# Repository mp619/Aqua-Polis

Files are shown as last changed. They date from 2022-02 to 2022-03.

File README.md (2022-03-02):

# Imperial College EEE - ELEC60013 Embedded Systems

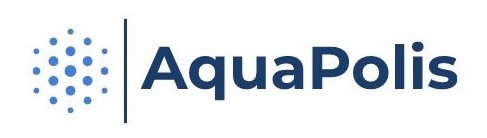
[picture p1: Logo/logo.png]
akt text


## Aquapolis

We often focus on the scarcity of water, yet the quality of it is as problematic: unsafe
water is in the top 15 causes of death worldwide, counting more than 1.2 million
victims only in 2017, as a study by the OurWorldInData highlights. This does not
affect only rural areas but also urban ones, as in the recent case of the Flint Water
Crisis.

In addition to health implications, this represents an environmental and economical problem as well: as reported from the CDP Global Water Report 2020, water
security is a necessary issue to solve in order to achieve our Net Zero Goal and the
multiple studies indicates how the financial impact of water risks is more than 5
times greater than the cost of addressing them.

The first step to solve this problem is to have a closer insight into the quality of the
water globally, integrating the data sets already present with new data collected by
individuals and institutions on a local scale. We believe that only through collective
intelligence we can assure our model and predictions are up to date and can meet
the highest quality standards.

From this vision was born AquaPolis, a network of IoT water sensors that can provide an accessible solution both in the immediate and long-term future. Each device can collect measurements of the water’s quality at any time, generating predictions on its potability based on a Machine Learning Model trained on big, verified
data sets. In addition, the new data, uploaded on a map, helps the model make better predictions in the future, keeping track of the values locally and creating a more
accurate view of the water situation globally.

## Structure

```bash
.
├───communication             # Communication testing files
├───Logo                      # Logo
├───Main                      # Raspi Source Files with modules
├───Miscellaneous             # Diagrams and MATLAB files for user guide
├───ML models                 # ML models
├───Protype                   # 3D CAD Files
├───SensorModules             # Sensor Module Testing Files
│   └───__pycache__
├───Sensors                   # Sensor Testing
│   └───SensorModules
└───user guide                # Diagrams for user guide
```

## Requirements

- [Raspberry Pi Zero W](https://www.raspberrypi.com/products/raspberry-pi-zero-w/)
- [CQRobot Ocean - TDS Sensor](https://www.amazon.co.uk/CQRobot-Ocean-Compatible-Scientific-Laboratory/dp/B08KXRHK7H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)
- [Gravity - Analog Turbidity Sensor](https://thepihut.com/products/gravity-analog-turbidity-sensor-for-arduino)
- [RGB LED - Common Anode](https://www.switchelectronics.co.uk/rgb-5mm-led-common-anode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)
- Button
- Python Modules
  - [numpy](https://numpy.org)
  - [pandas](https://pandas.pydata.org)
  - [sklearn](https://scikit-learn.org/stable/)
  - [seaborn](https://pypi.org/project/seaborn/)
  - [tensorflow](https://www.tensorflow.org)
  - [joblib](https://pypi.org/project/joblib/)
  - [cryptography](https://pypi.org/project/cryptography/)
  - [Threading](https://docs.python.org/3.9/library/threading.html)
  - [Time](https://docs.python.org/3.9/library/time.html)
  - [smbus2](https://pypi.org/project/smbus2/)
  - [paho-mqtt](https://pypi.org/project/paho-mqtt/)
  - [datatime](https://docs.python.org/3.9/library/datetime.html)
  - [json](https://docs.python.org/3.9/library/json.html)
  - [dateutil](https://dateutil.readthedocs.io/en/stable/)
  - [requests](https://pypi.org/project/requests/)
  - local - [TDS](https://github.com/mp619/Aqua-Polis/blob/master/Main/TDS.py)
  - local - [Turbidity](https://github.com/mp619/Aqua-Polis/blob/master/Main/Turbidity.py)
  - local - [RGB](https://github.com/mp619/Aqua-Polis/blob/master/Main/RGB.py)

## Setup
- Connect components to approtiate pins on to the Raspberry Pi
- [Download](https://www.python.org/downloads/) and install Python 3.9
- Install relevent external modules
- Transfer \Main to Raspberry Pi
- Run main2.py with in \Main containing full program

## Additonal Reference
- Please see [ADS1115](https://www.ti.com/lit/ds/symlink/ads1114.pdf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) datasheet for further reading into sensor register intialization via I2C
- Please refer to [WebApp](https://imperiallondon-my.sharepoint.com/:f:/g/personal/st819_ic_ac_uk/EoQVA6fin6ZFqeSijLbOCq8BSeelOjj9dkYSWtxEH0-T_A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) shared folder for full flutter web interface implementation

## Links
- [Website](https://aquapolis23.web.app/#/)
- [Video](https://www.youtube.com/watch?v=wYGQqHpmxyM&ab_channel=MartinPrusa)
- [User Guide](https://github.com/mp619/Aqua-Polis/blob/master/user%20guide/Aquapolis_User_Guide-2.pdf)
- [Instagram](https://www.instagram.com/aqua_polis_official/)
- [Source Code](https://github.com/mp619/Aqua-Polis)

## Examples

akt text
akt text

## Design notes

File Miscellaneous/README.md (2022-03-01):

# Aqua-Polis

To do:

Mati:
- [x] website, 
- [ ] user guide
- [x] prototype and print

Salman:
- [ ] encription
- [x] video script

Sam:
- [x] map and user
- [ ] video editing

Martin:
- [x] led
- [ ] datasheet about threading and co

All: 
- [ ] video
- [ ] testing and demo simulation

--communication--
- [x] Com raspberry-broker
- [x] Com sensors-raspberry
- [x] Com rasp-server
- [x] Com server-app
- [ ] Encription

--basic functionality--
- [x] Sensors
- [x] Server
- [x] Broker
- [x] Raspberry  
- [x] ML model (Neural, classification problem, trained on dataset and test on new data uploaded)

--high level deliverables--
- [x] Web app
- [ ] Mobile app
- [x] general page
- [-] User login info
- [x] User location
- [x] Data analysis and statistics
- [ ] User guide (stir and move it around, 10*10 average), led lights signals
- [x] Map (When creating the map need to select what source of water used e.g. Tap, river, fountain..)
- [x] socials
- [ ] video
- [x] video script
- [x] prototype and print

--Sensor hardware and power--
- [x] Turbidity
- [x] TDS
- [x] LED 
- [x] button
- [[]] Advanced model: Battery, More sensors, Temperature compensation ?
- [ ] !! Connection safety (mqtt QOS type 2, highest level of service), missing connection on raspberry pi, flashing red light
- [x] error handling more on range of sensor values?

-- Marketing page --
- What: potability and water security (data to stress on the urgency of this problem)
- Where: urban and rural areas application
- When: anytime sensor functionality plus additional features with stable network
- Why: social target, water quality problem and safe water sources
- Who: costumer target, anyone who has this device and a phone
- Marketing analysis

-- Advanced --
- [x] Event queue (wait for ml result in a lopp ...)
- [x] threading (2 sensors, 1 bus, threading with led and button, reading + website server?)
- [x] Calibration
- [[]] Additional sensors
- [x] CAD prototype
- [x] Second marketing page with advanced version (only prototype due to external project constraints)
- [x] Creative way of using Python classes (ML model)



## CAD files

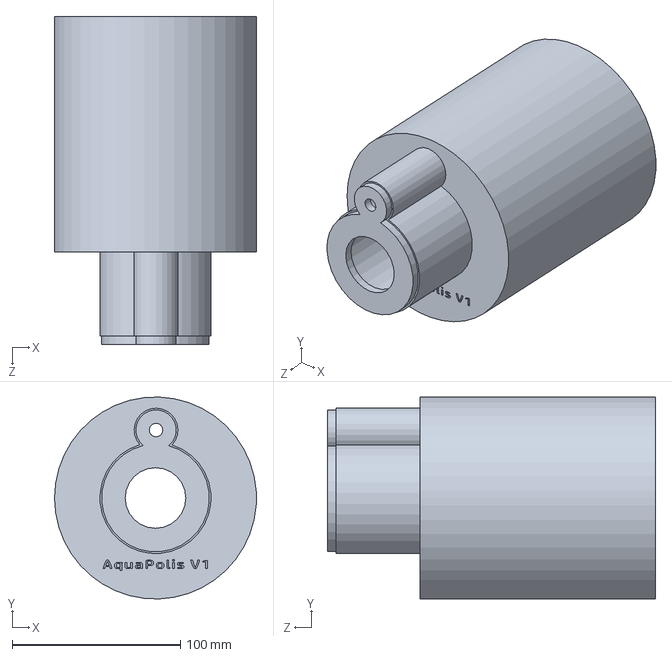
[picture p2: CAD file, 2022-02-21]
Protype/AquaPolisV1.SLDPRT
120.0 x 119.9 x 195.0 mm

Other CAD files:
Protype/AquaPolisV1.STL

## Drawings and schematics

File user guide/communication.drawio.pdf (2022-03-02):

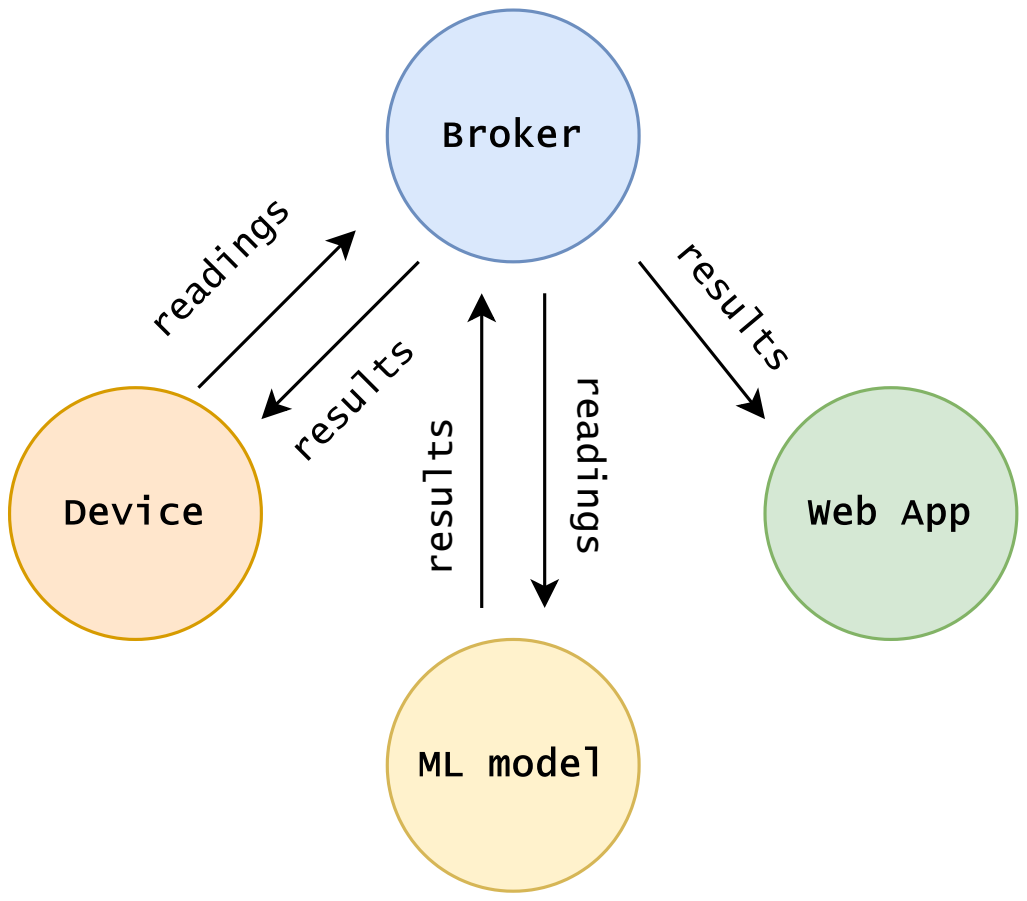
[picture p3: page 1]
Broker; Device; Web App; ML modelreadings; results; readings

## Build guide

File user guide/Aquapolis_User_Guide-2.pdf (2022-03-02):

## AQUALINK 1.0

## USER GUIDE

1SECTION

# Why Aquapolis?

### 1.1 The water crisis:

We often focus on the scarcity of water, yet the quality of it is as problematic: unsafe water is in the top 15 causes of death worldwide, counting more than 1.2 million victims only in 2017, as a study by the OurWorldInData highlights. This does not affect only rural areas but also urban ones, as in the recent case of the Flint Water Crisis.
In addition to health implications, this represents an environmental and economical problem as well: as reported from the CDP Global Water Report 2020, water security is a necessary issue to solve in order to achieve our Net Zero Goal and the multiple studies indicates how the financial impact of water risks is more than 5 times greater than the cost of addressing them.

### 1.2 Our solution:

The first step to solve this problem is to have a closer insight into the quality of the water globally, integrating the data sets already present with new data collected by individuals and institutions on a local scale. We believe that only through collective intelligence we can assure our model and predictions are up to date and can meet the highest quality standards.

1

From this vision was born AquaPolis, a network of IoT water sensors that can provide an accessible solution both in the immediate and long-term future. Each device can collect measurements of the water’s quality at any time, generating predictions on its potability based on a Machine Learning Model trained on big, verified data sets. In addition, the new data, uploaded on a map, helps the model make better predictions in the future, keeping track of the values locally and creating a more accurate view of the water situation globally.

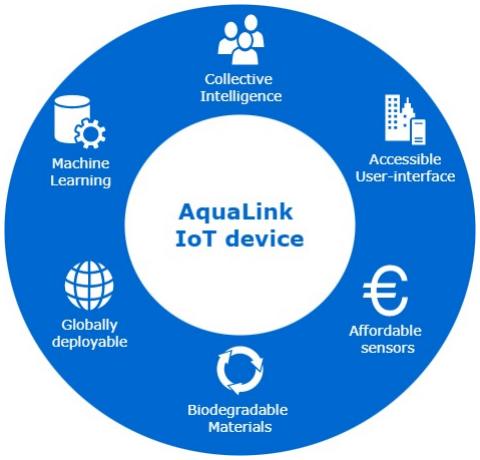
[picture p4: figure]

2

2SECTION

# AquaLink 1.0 specification

### 2.1 The product:

AquaLink 1.0 is the first product by AquaPolis, an IoT device which measures the quality of the water based on its turbidity and amount of solid particles and uses a Machine Learning Model to accurately predict whether the water is safe to drink. The information on the quality of the water collected by AquaLink, together with the location of the water source, are recorded on a map accessible on our website. This provides the user with an accurate history of the water quality measurements of their local sources.

### 2.2 Machine Learning model:

Our machine learning model consists of an ensemble of random forests which take in the received data from on-board sensors to determine the potability of water. Alongside extensive data pre-processing during training, our models have undergone extensive hyper-parameter tuning to ensure a high level of accuracy during classification.

3

### 2.3 Specifications:

Aquapolis | Model: 1.0
| Wireless Communication: Wifi (MQTT) Measuring methods: TDS and TSS Multi-use Package includes rechargable battery, raspberry pi, travel case

Dimensions 12 cm x 8 cm x 3 cm
| Power: 36.5Wh, 5V
Accuracy | TDS: 0 - 1000ppm; 100samples/sec TSS: 0-5 NTU; 100samples/sec
Operation | Operating temperature: 0 - 55◦

### 2.4 The communication:

The device uses a subscribe-publish model on MQTT where our own broker is hosted on a server and routes information to the three clients in our system: device with the sensors, machine learning model, and the web app.

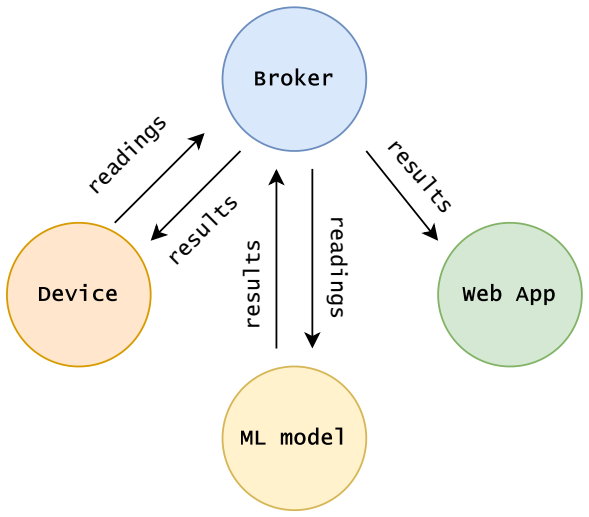
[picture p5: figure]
Broker; Device; Web App; ML modelreadings; results; readings

Figure 1: Encrypted communication diagram

Encryption has been implemented in the communication process between the device, broker and webapp to ensure the safeguarding of your personal data whether you are at home or abroad.

4

### 2.5 Calibration

Our sensors are individually calibrated using a series of pre-made solutions. This has allowed for a line of best fit to be calculated and saved in the memory of the Raspberry Pi (2). Hence the user can be sure that the sensor is reading all the data correctly and sending to appropriate values to the machine learning model.

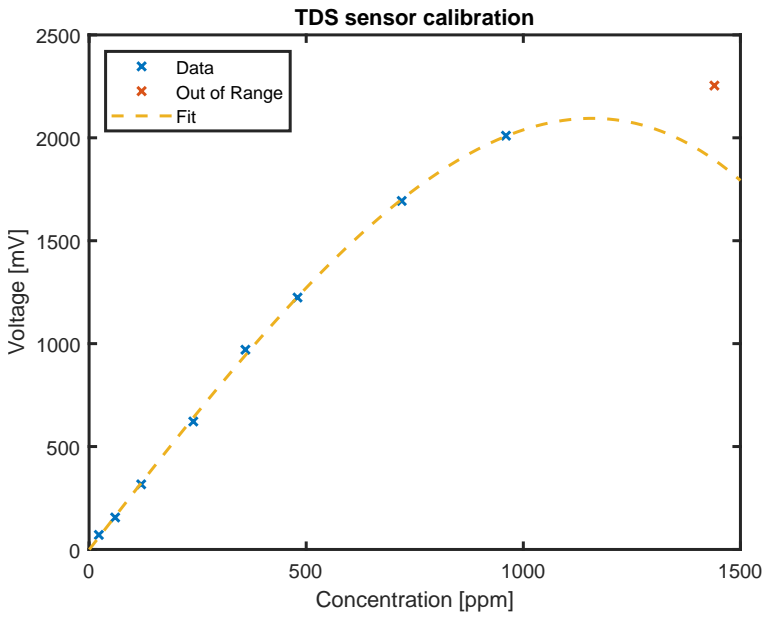
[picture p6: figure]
Concentration [ppm]; Voltage [mV]; TDS sensor calibration; Data Out of Range Fit

Figure 2: TDS calibration

### 2.6 Threading

Our design incorporates the multi-threading capabilities of the Raspberry Pi to enable seamless operation between the status LED and the operation of the sensors. A global variable is used to pass the status condition of the program to the LED subsystem in a separate thread.

5

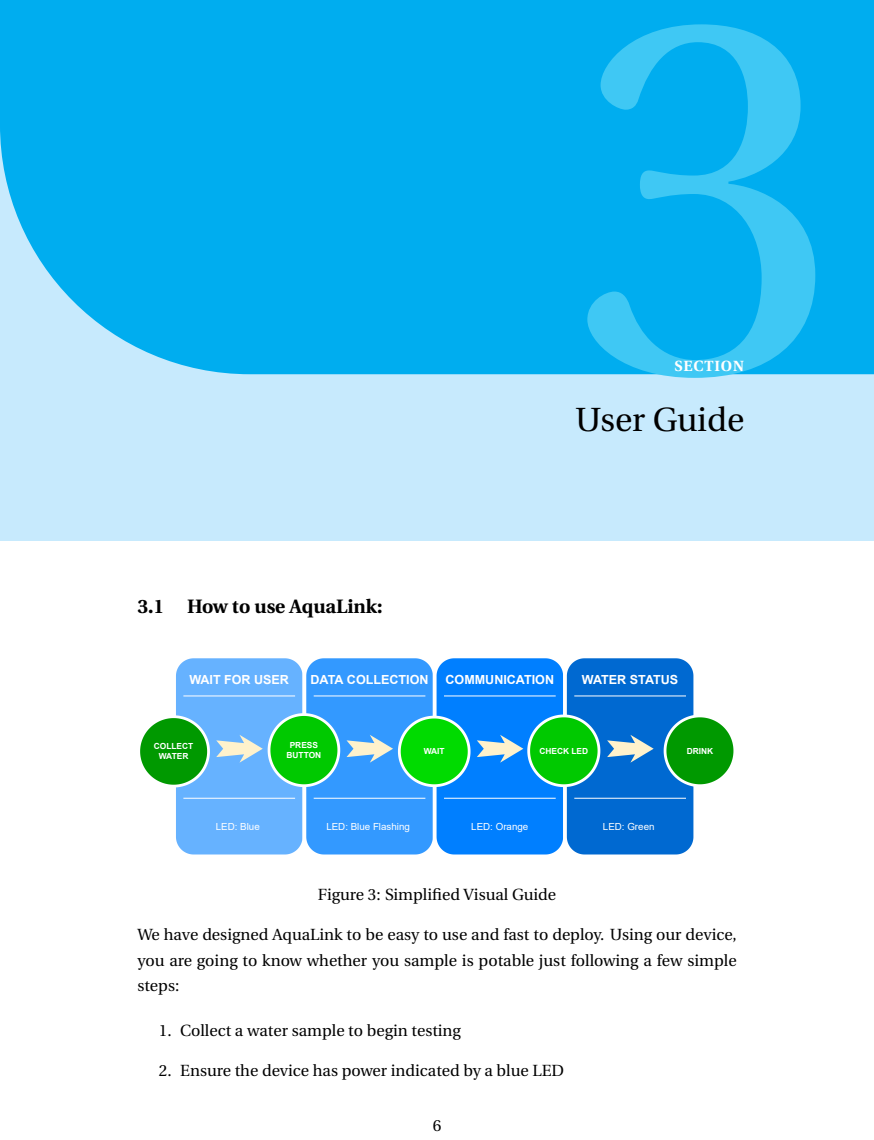
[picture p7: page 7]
3SECTION; User Guide; LED: Blue; DATA COLLECTION; COMMUNICATION; LED: Orange; WATER STATUS; LED: Green; WAIT; CHECK LED; DRINK PRESS; BUTTON; COLLECT WATER

3.1 How to use AquaLink: WAIT FOR USER

LED: Blue Flashing

Figure 3: Simplified Visual Guide

We have designed AquaLink to be easy to use and fast to deploy. Using our device,
you are going to know whether you sample is potable just following a few simple
steps:

1. Collect a water sample to begin testing

2. Ensure the device has power indicated by a blue LED 6

3. Simply place device with both sensors fully in the water. Make sure that the metal contacts are fully submerged away from the container edges.
4. Press the button to begin water analysis. The LED debugging codes can be found in table 1
5. A GREEN LED indicates the water is safe to drink.
6. A RED LED indicates the water is NOT safe to drink
7. Another reading can be made by pressing the button again
LED Colour | Description
Green | Water is clean - Good to drink
Red | Water is dirty - Bad to drink
Blue | Circuit is powered and on
Blue Flashing Sensing water quality
Orange | Communicating with server
Red Flashing | Communication has failed - Restart Device

Table 1: LED colour codes

7

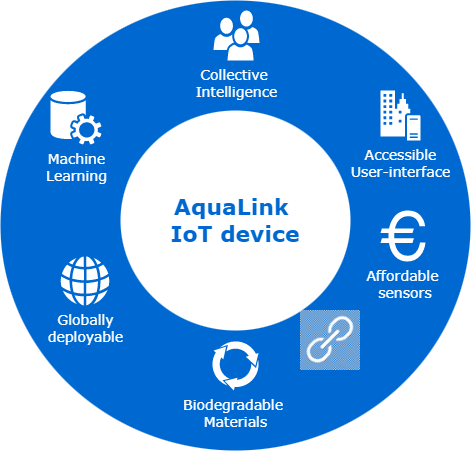
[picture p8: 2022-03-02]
user guide/AquaLink_fehfuiweugniwutures.png

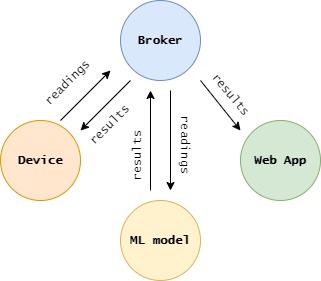
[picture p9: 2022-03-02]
user guide/communication.jpg

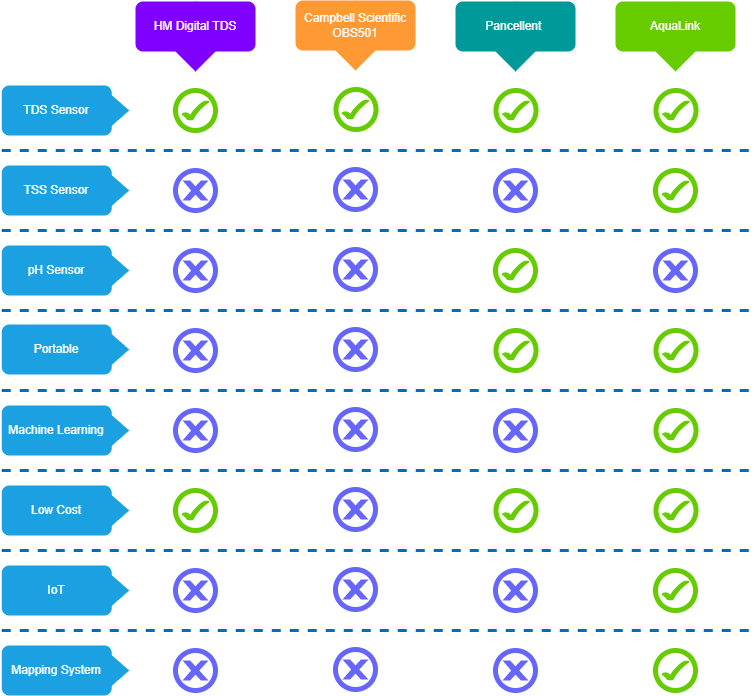
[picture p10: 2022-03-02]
user guide/ComparisonChart.drawio.png

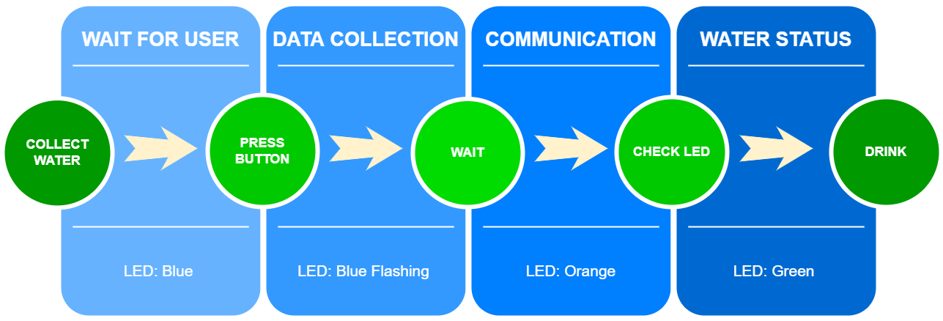
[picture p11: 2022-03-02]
user guide/User Guide.png

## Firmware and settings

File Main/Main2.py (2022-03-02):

from threading import Thread
import time
import smbus2
import TDS as TDS
import Turbidity as Turb
import RGB
import paho.mqtt.client as mqtt
import datetime
import json
from dateutil.tz import tzutc
import requests
from cryptography.hazmat.backends import default_backend
from cryptography.hazmat.primitives import serialization
from cryptography.hazmat.primitives import hashes
from cryptography.hazmat.primitives.asymmetric import padding

key_file = open("rprivate-key.pem", "rb")
private_key = serialization.load_pem_private_key(
    key_file.read(),
    password=None,
    backend=default_backend()
)

key_file = open("public-key.pem", "rb")
public_key = serialization.load_pem_public_key(
    key_file.read(),
    backend=default_backend()
)

#Global Variable for LED Thread
STATUS = 1

def on_connect(client, userdata, flags, rc):
    global STATUS
    print(rc)
    if rc ==0:
        print("Successful Connection")
        #print("Connected with result code "+str(rc))
        client.subscribe("IC.embedded/M2S2/#")
        STATUS = 6
    else:
        print("Bad Connection, returned code=", rc)
        STATUS = 7


def on_message(client, userdata, message) :
    global STATUS
    print("Received message:{} on topic{}".format(message.payload, message.topic))
    if(message.topic=="IC.embedded/M2S2/results"):
        original_message = private_key.decrypt(message.payload,
                                                padding.OAEP(mgf=padding.MGF1(algorithm=hashes.SHA256()),
                                                            algorithm=hashes.SHA256(),
                                                            label=None
                                                            )
                                                )
        # decode and turn from json to dict 
        data = str(original_message.decode())
        drink = data.split()[0]
        print(drink)
        if drink == 'True':
            STATUS = 2
        else:
            STATUS = 3
#        client.loop_stop()

#MQTT
client = mqtt.Client()
#client.tls_set(ca_certs="mosquitto.org.crt",certfile="client.crt",keyfile="client.key")
try :
    client.connect("146.169.199.233",port=1883)
    STATUS = 6
except:
    STATUS = 7
#client.on_connect = on_connect
client.subscribe("IC.embedded/M2S2/#")
client.on_message = on_message
client.on_publish = print('Published readings to broker')
client.on_subscribe = print('Subscribed to all topics')

#temp_array = []

# Init Objects
bus = smbus2.SMBus(1)
led = RGB.RGBInit()
button = RGB.ButtonInit()

#TDS Config
ADC_adr = 0x48 # ADC I2C address

# 1 Turns off LED
# 2 Clean - Green
# 3 Dirty - Red
# 4 Processing - Blue flashing
# 5 Sending/Receiving - Yellow
# 6 Before Button Press - Blue
# 7 Comms Failed - Red Flashing

def ledcolor():
    global STATUS
    while STATUS:
        if STATUS == 1:
            RGB.StatusOff(led)
        elif STATUS == 2:
            RGB.StatusClean(led)
        elif STATUS == 3:
            RGB.StatusDirty(led)
        elif STATUS == 4:
            RGB.StatusMeasuring(led)
        elif STATUS == 5:
            RGB.StatusSending(led)
        elif STATUS == 6:
            RGB.StatusOn(led)
        elif STATUS == 7:
            RGB.StatusFailSending(led)
        else:
            break

def Json_create( TDS_value, Turb_Value, Lon, Lat ):
    a_datetime = datetime.datetime.now()
    time_stamp = a_datetime.isoformat()
    Reading_dic = {
        'TimeStamp': time_stamp,
        'TDS': TDS_value,
        'TSS': Turb_Value,
        'Lon': Lon,
        'Lat': Lat
    }
    json_output = json.dumps(Reading_dic)
    return json_output

LED_Thread = Thread(target=ledcolor)
LED_Thread.start()
#Message_Thread = Thread(target=client.loop_forever())
#Message_Thread.start()

while True:
    client.reconnect()
    if RGB.Press(button):
        print('Button Pressed...')
        ## Get TDS and Turb value
        STATUS = 4  # Processing 
        TDS_Total = 0
        Turb_Total = 0
        cycles = 100

        ## Get TDS value
        for i in range(1,cycles):
            TDS.config(bus, ADC_adr)
            time.sleep(0.01)
            TDS_Total = TDS_Total + TDS.read(bus, ADC_adr)
        TDS_adc = TDS_Total/cycles
        TDS_value = TDS.convert(TDS_adc)

        ## Get Turb value
        for i in range(1,cycles):
            Turb.config(bus, ADC_adr)
            time.sleep(0.01)
            Turb_Total = Turb_Total + Turb.read(bus, ADC_adr)
        Turb_adc = Turb_Total/cycles
        print(Turb_adc)
        Turb_value = Turb.convert(Turb_adc)

        print(TDS_value, 'ppm')
        print(Turb_value, 'NTU')

        ## Get Long and Lat to seen
        try:
            url = 'https://extreme-ip-lookup.com/json/'
            r = requests.get(url)
            data = json.loads(r.content.decode())
            ip = data['query']
            response = requests.get("https://geolocation-db.com/json/"+ip+"&position=true").json()
            lat = response['latitude']
            lon = response['longitude']
            print("Latitude: ", lat)
            print("Longitude: ", lon)
        except:
            # ideally a GPS module would be used to collect location data
            lat = 51.4963
            lon = -0.1769

        ## Send to broker
        STATUS = 5
        json_output = Json_create( TDS_value, Turb_value, lat, lon)
        print(json_output)
        json_output = json_output.encode()
        encMessage = public_key.encrypt(json_output,padding.OAEP(mgf=padding.MGF1(algorithm=hashes.SHA256()),algorithm=hashes.SHA256(),label=None))
        MSG_INFO= client.publish("IC.embedded/M2S2/readings",json_output)
        print(mqtt.error_string(MSG_INFO.rc))
        client.loop_start()

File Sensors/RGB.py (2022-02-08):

import time
from gpiozero import RGBLED, Button
from colorzero import Color

led = RGBLED(22, 27, 17, False) # This is a common anode type RBG LED
button = Button(18, False) # The Raspi will pull up the button
while True:
    if button.is_held:
        led.color = Color('yellow')
    else:
        led.off()
    

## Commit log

2022-02-08 Sensor Tests Done
2022-02-09 Added water dataset
    [water_potability.csv]
2022-02-09 both sensors
2022-02-16 Completed Calibration
    [TDS Data Real.xlsx]
2022-02-16 Calibration Completed
2022-02-18 Button and RGB module
2022-02-18 RGB and Button
2022-02-18 Threading Test
2022-02-21 LED Threading Working
2022-02-28 Added more LED Functionality
2022-03-01 Rm Files
    [TDS Data Real.xlsx]
2022-03-02 tidying up
    [water_potability.csv]
